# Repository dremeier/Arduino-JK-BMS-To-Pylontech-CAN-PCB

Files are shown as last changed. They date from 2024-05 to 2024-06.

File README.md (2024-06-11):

<div align = center>

# [Arduino JK-BMS to Pylontech-CAN PCB](https://github.com/dremeier/Arduino-JK-BMS-To-Pylontech-CAN-PCB) 

PCB and Case for the Arduino JK-BMS To Pylontech-CAN converter for Deye Inverter
<br/>
  
 
<br/>
<div align = left>
  
## Arduino Firmware by Armin: https://github.com/ArminJo/JK-BMSToPylontechCAN 

#### If you find this program useful, please give it a star.

&#x1F30E; [Google Translate](https://translate.google.com/translate?sl=en&u=https://github.com/dremeier/Arduino-JK-BMS-To-Pylontech-CAN-PCB)

## Features 
- Buck converter for up to 65 Volt to 5V.
- RS232-stream from the BMS translate from 3,3V to 5V and are galvanic seperated.
- MCU ATmega644P with [MightyCore](https://github.com/MCUdude/MightyCore) Bootloader.
- Connectors are JST PH S4B-PH-K 1x04 P2.00mm Horizontal.
- RJ45 connector Amphenol 54602-x08 Horizontal.
- Designed with KiCad 8.

[Files to print your own case](JK-BMS-CAN_Case/)

## Pictures

### PCB Layout
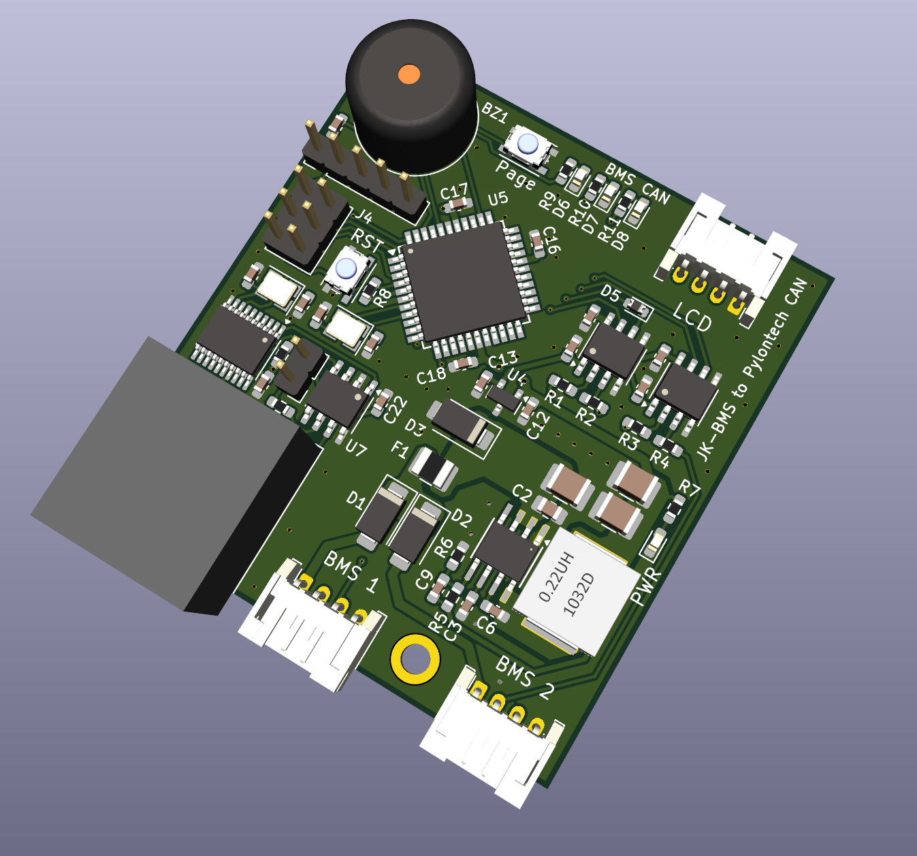
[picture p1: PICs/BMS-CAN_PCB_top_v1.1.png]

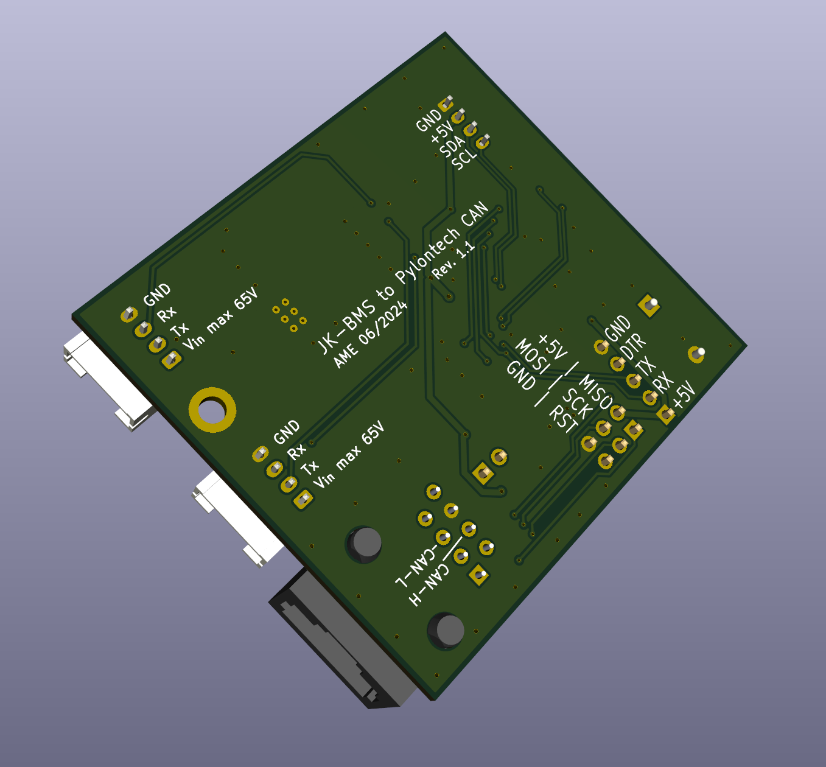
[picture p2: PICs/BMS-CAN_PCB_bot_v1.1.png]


### Aufbau im Gehäuse
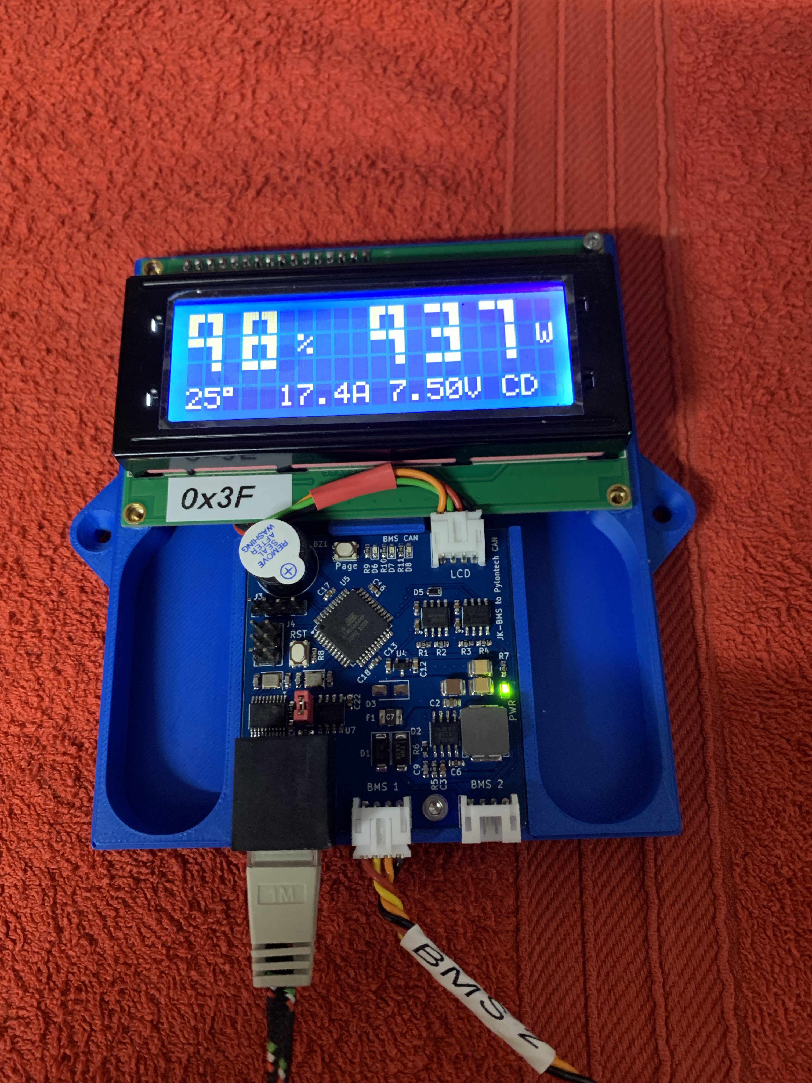
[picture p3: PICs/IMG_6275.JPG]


### Fertig installiert mit einem BMS, die Verarbeitung für das 2. BMS ist in Arbeit
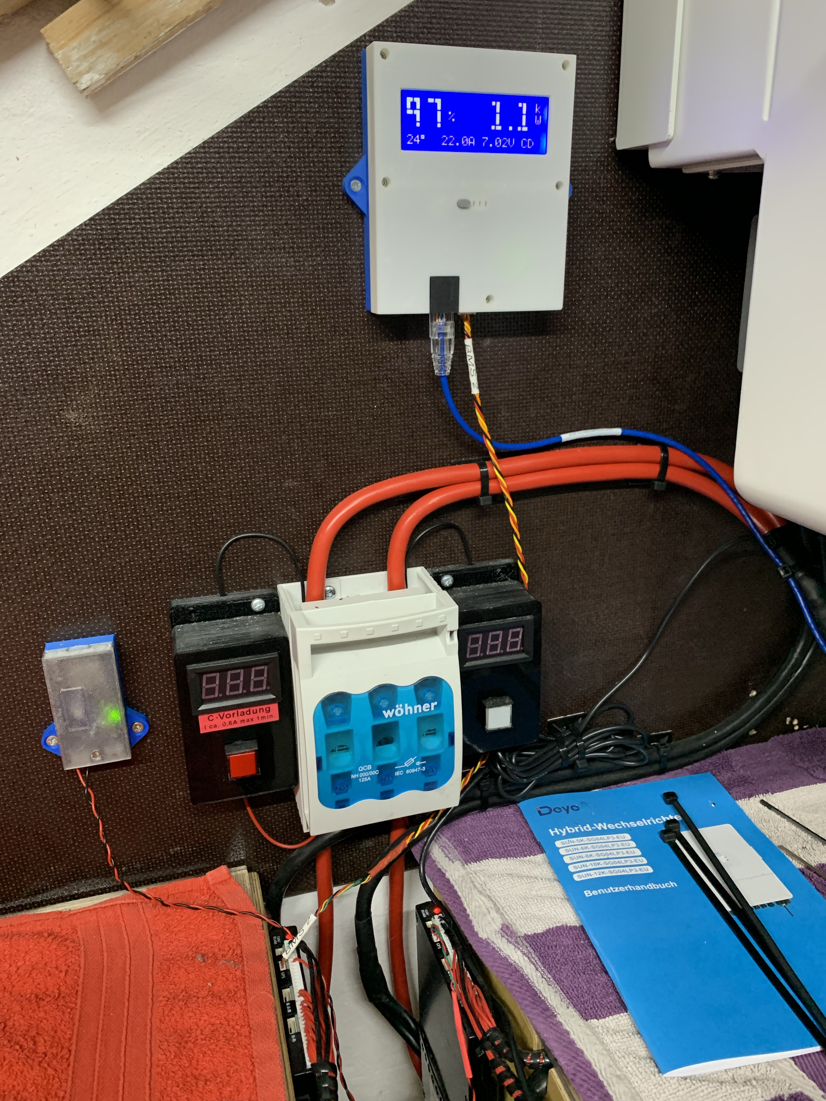
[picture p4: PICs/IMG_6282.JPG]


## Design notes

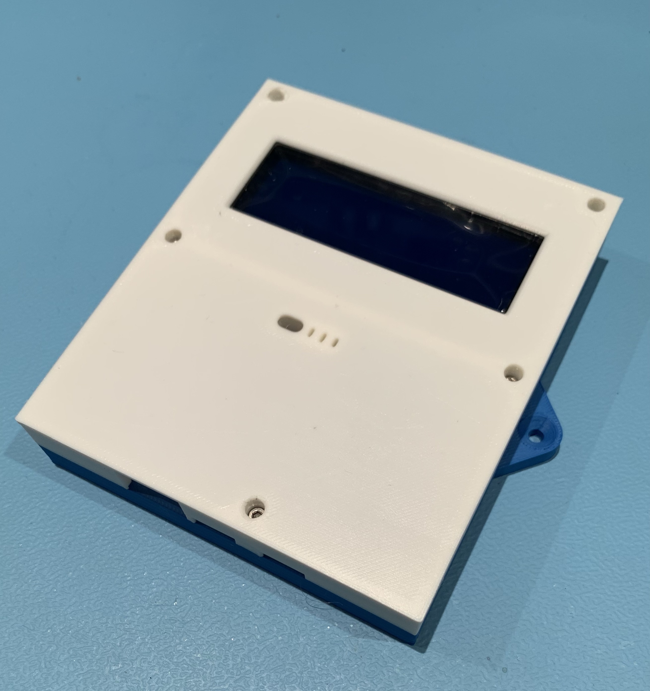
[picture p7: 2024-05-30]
PICs/BMS-CAN_Case.JPG

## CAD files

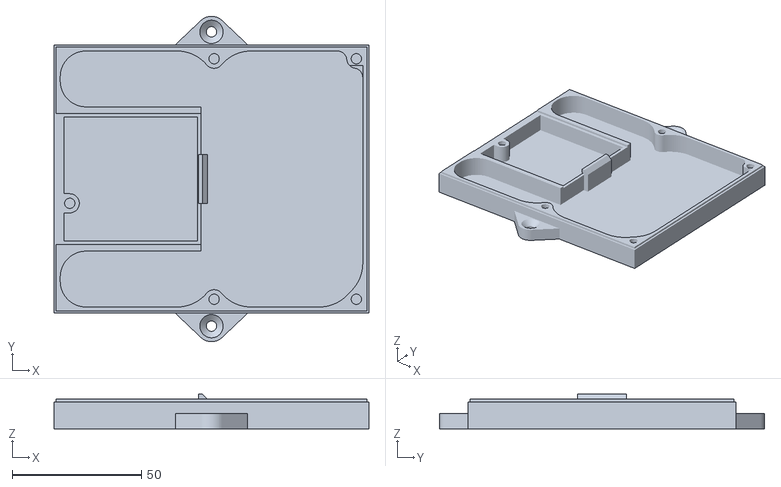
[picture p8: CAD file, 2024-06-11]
JK-BMS-CAN_Case/Boden.stl
121.8 x 125.8 x 13.5

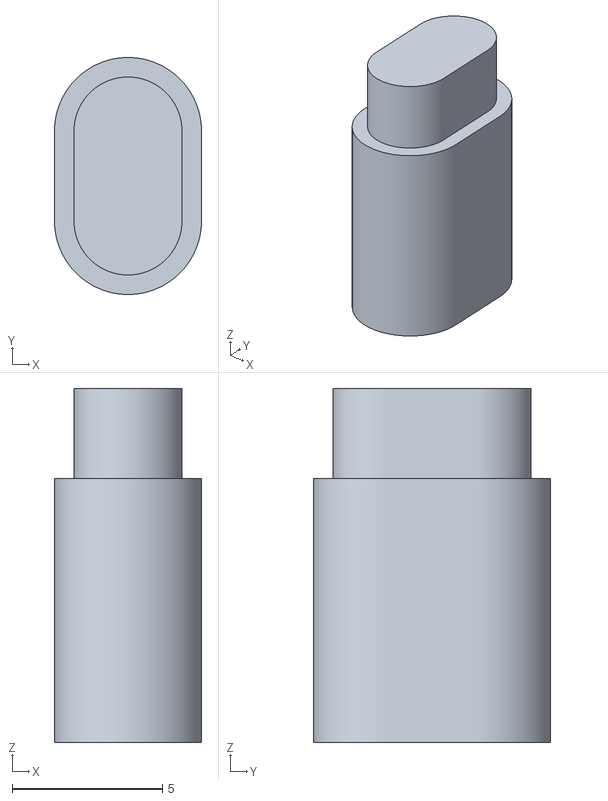
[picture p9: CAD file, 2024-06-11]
JK-BMS-CAN_Case/Taster.stl
4.90 x 7.90 x 11.8

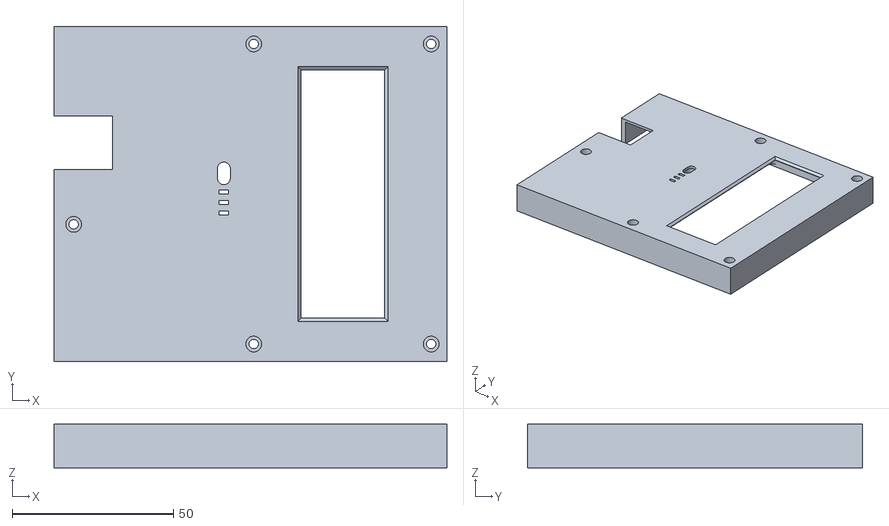
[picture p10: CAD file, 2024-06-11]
JK-BMS-CAN_Case/Deckel.stl
121.8 x 103.8 x 13.5

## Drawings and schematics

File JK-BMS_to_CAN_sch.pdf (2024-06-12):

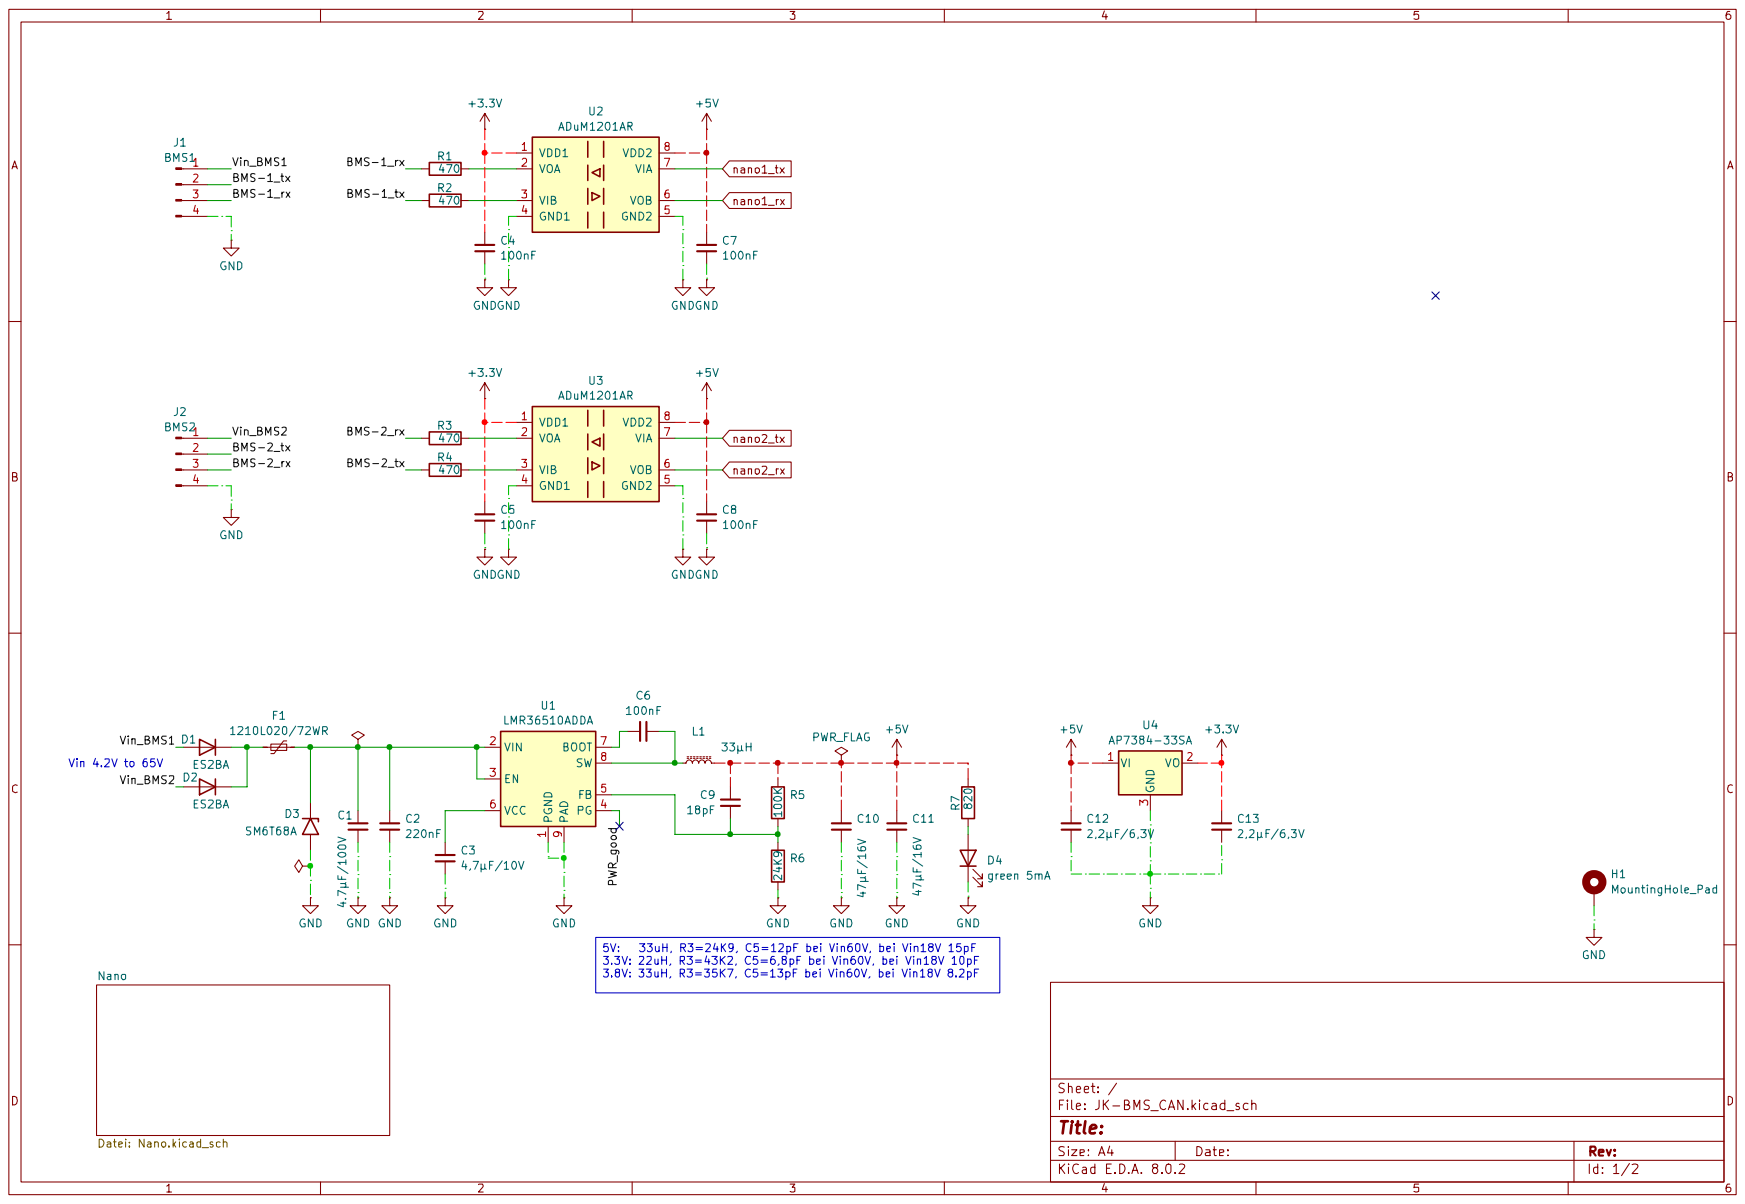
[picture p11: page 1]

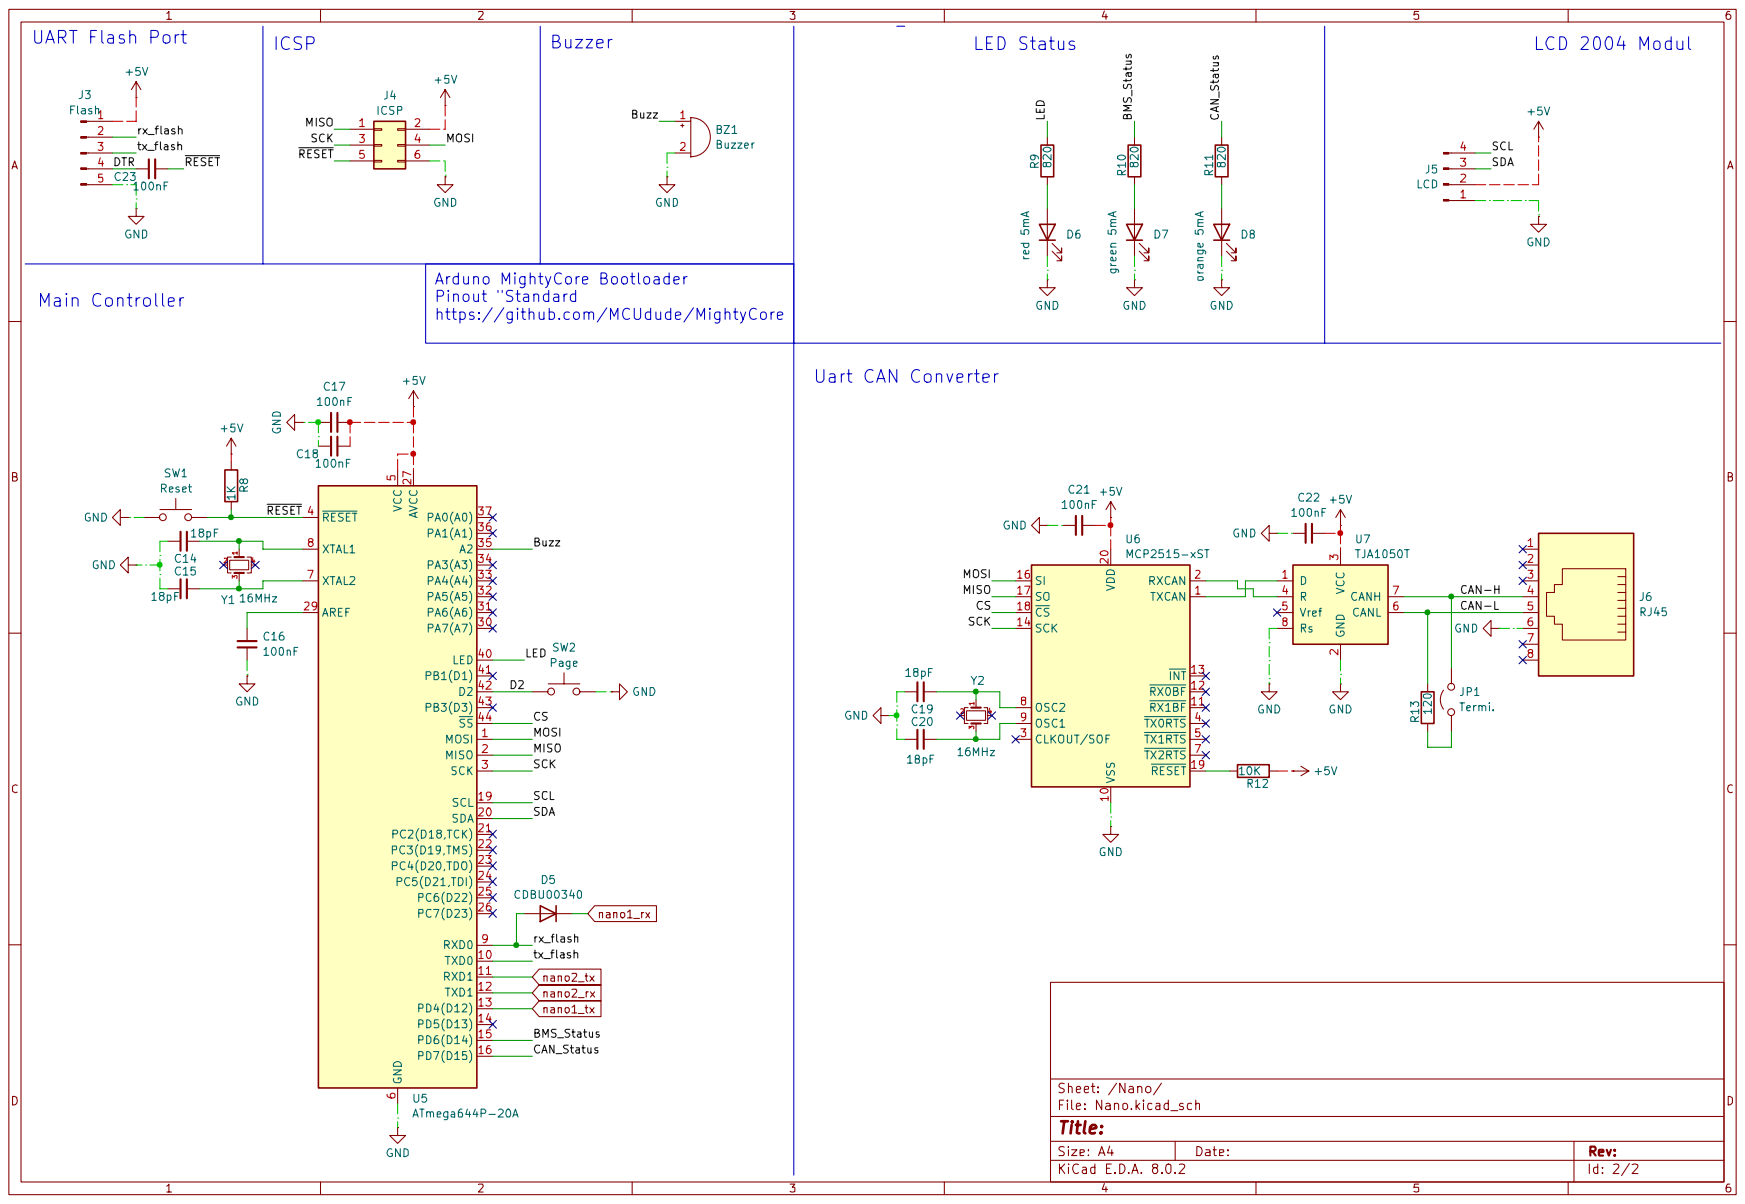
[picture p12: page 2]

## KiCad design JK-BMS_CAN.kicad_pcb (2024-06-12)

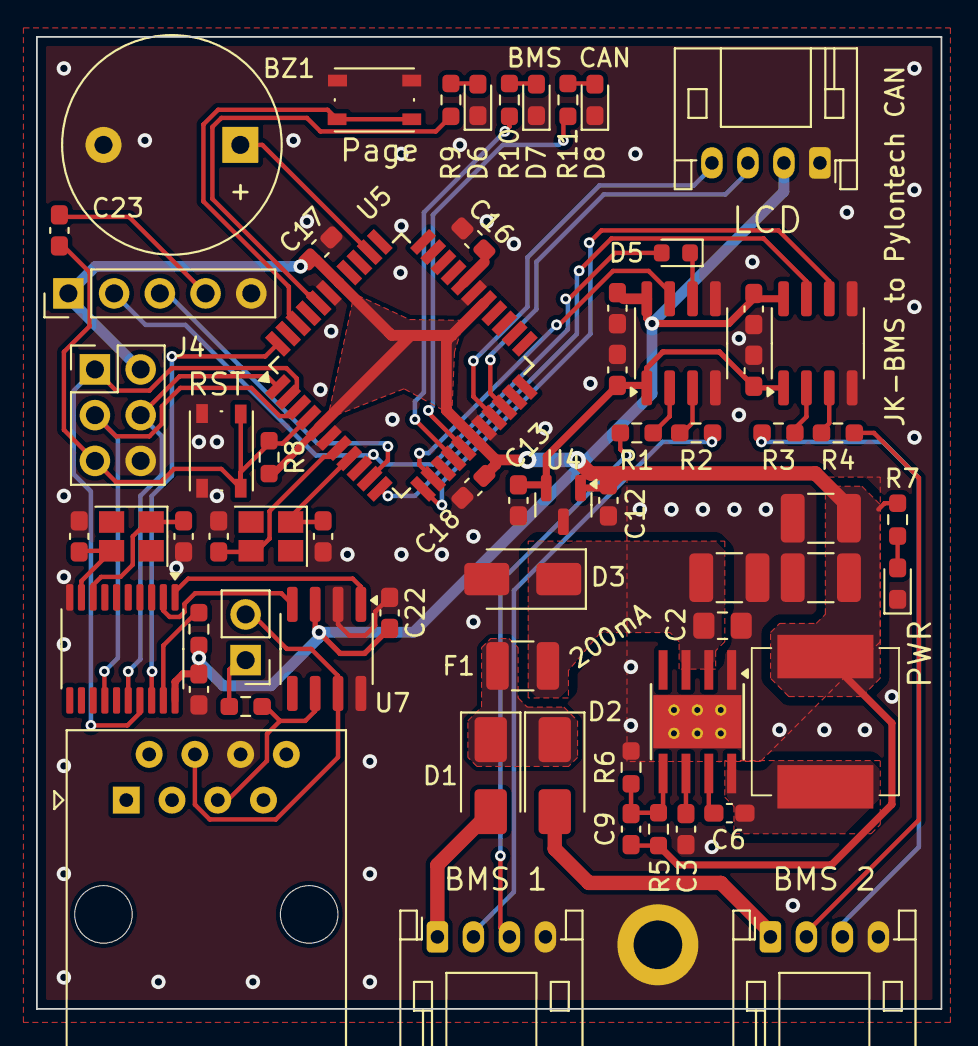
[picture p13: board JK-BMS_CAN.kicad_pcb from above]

Board: 2 copper layers, 50.2 x 54.0 mm, 66 parts (0 on the bottom side), 53 nets.

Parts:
BZ1: Buzzer; Buzzer_12x9.5RM7.6
C1: 4.7µF/100V; C_1210_3225Metric_Pad1.33x2.70mm_HandSolder
C2: 220nF; C_0805_2012Metric_Pad1.18x1.45mm_HandSolder
C3: 4,7µF/10V; C_0603_1608Metric_Pad1.08x0.95mm_HandSolder
C4, C5, C6, C7, C8, C16, C17, C18, C21, C22, C23: 100nF; C_0603_1608Metric_Pad1.08x0.95mm_HandSolder
C9, C14, C15, C19, C20: 18pF; C_0603_1608Metric_Pad1.08x0.95mm_HandSolder
C10, C11: 47µF/16V; C_1210_3225Metric_Pad1.33x2.70mm_HandSolder
C12, C13: 2,2µF/6,3V; C_0603_1608Metric_Pad1.08x0.95mm_HandSolder
D1, D2: ES2BA; D_SMA
D3: SM6T68A; D_SMA
D4, D7: green 5mA; LED_0603_1608Metric_Pad1.05x0.95mm_HandSolder
D5: CDBU00340; D_0603_1608Metric
D6: red 5mA; LED_0603_1608Metric_Pad1.05x0.95mm_HandSolder
D8: orange 5mA; LED_0603_1608Metric_Pad1.05x0.95mm_HandSolder
F1: 1210L020/72WR; Fuse_1210_3225Metric
H1: MountingHole_Pad; MountingHole_2.7mm_M2.5_ISO7380_Pad
J1: BMS1; JST_PH_S4B-PH-K_1x04_P2.00mm_Horizontal
J2: BMS2; JST_PH_S4B-PH-K_1x04_P2.00mm_Horizontal
J3: Flash; PinHeader_1x05_P2.54mm_Vertical
J4: ICSP; PinHeader_2x03_P2.54mm_Vertical
J5: LCD; JST_PH_S4B-PH-K_1x04_P2.00mm_Horizontal
J6: RJ45; RJ45_Amphenol_54602-x08_Horizontal
JP1: Termi.; PinHeader_1x02_P2.54mm_Vertical
L1: 33µH; IHLP3232DZER330M11
R1, R2, R3, R4: 470; R_0603_1608Metric_Pad0.98x0.95mm_HandSolder
R5: 100K; R_0603_1608Metric_Pad0.98x0.95mm_HandSolder
R6: 24K9; R_0603_1608Metric_Pad0.98x0.95mm_HandSolder
R7, R9, R10, R11: 820; R_0603_1608Metric_Pad0.98x0.95mm_HandSolder
R8: 1K; R_0603_1608Metric_Pad0.98x0.95mm_HandSolder
R12: 10K; R_0603_1608Metric_Pad0.98x0.95mm_HandSolder
R13: 120; R_0603_1608Metric_Pad0.98x0.95mm_HandSolder
SW1: Reset; SW_Push_1P1T_NO_Vertical_Wuerth_434133025816
SW2: Page; SW_Push_1P1T_NO_Vertical_Wuerth_434133025816
U1: LMR36510ADDA; Texas_HTSOP-8-1EP_3.9x4.9mm_P1.27mm_EP2.95x4.9mm_Mask2.4x3.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
U2, U3: ADuM1201AR; SOIC-8_3.9x4.9mm_P1.27mm
U4: AP7384-33SA; SOT-23
U5: ATmega644P-20A; TQFP-44_10x10mm_P0.8mm
U6: MCP2515-xST; TSSOP-20_4.4x6.5mm_P0.65mm
U7: TJA1050T; SOIC-8_3.9x4.9mm_P1.27mm
Y1, Y2: 16MHz; Crystal_SMD_Abracon_ABM8AIG-4Pin_3.2x2.5mm

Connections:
+3.3V: C4.1, C5.1, C13.1, U2.1 (VDD1), U3.1 (VDD1), U4.2 (VO)
+5V: C7.1, C8.1, C9.2, C10.1, C11.1, C12.1, C17.1, C18.1, C21.2, C22.2, J3.1, J4.2, J5.2, L1.2, R5.2, R7.1, R8.2, R12.2, U2.8 (VDD2), U3.8 (VDD2), U4.1 (VI), U5.5 (VCC), U5.17 (VCC), U5.27 (AVCC), U5.38 (VCC), U6.20 (VDD), U7.3 (VCC)
/BMS-1_rx: J1.3, R1.2
/BMS-1_tx: J1.2, R2.2
/BMS-2_rx: J2.3, R3.2
/BMS-2_tx: J2.2, R4.2
/Nano/BMS_Status: R10.1, U5.15 (PD6(D14))
/Nano/Buzz: BZ1.1 (+), U5.35 (A2)
/Nano/CAN-H: J6.4, JP1.2 (B), U7.7 (CANH)
/Nano/CAN-L: J6.5, R13.1, U7.6 (CANL)
/Nano/CAN_Status: R11.1, U5.16 (PD7(D15))
/Nano/CS: U5.44 (~SS), U6.18 (~CS)
/Nano/D2: SW2.1, U5.42 (D2)
/Nano/DTR: C23.2, J3.4
/Nano/LED: R9.1, U5.40 (LED)
/Nano/MISO: J4.1, U5.2 (MISO), U6.17 (SO)
/Nano/MOSI: J4.4, U5.1 (MOSI), U6.16 (SI)
/Nano/SCK: J4.3, U5.3 (SCK), U6.14 (SCK)
/Nano/SCL: J5.4, U5.19 (SCL)
/Nano/SDA: J5.3, U5.20 (SDA)
/Nano/rx_flash: D5.2 (A), J3.2, U5.9 (RXD0)
/Nano/tx_flash: J3.3, U5.10 (TXD0)
/Nano/~RESET: C23.1, J4.5, R8.1, SW1.2, U5.4 (~RESET)
/Vin_BMS1: D1.2 (A), J1.1
/Vin_BMS2: D2.2 (A), J2.1
GND: BZ1.2 (-), C1.2, C2.2, C3.2, C4.2, C5.2, C7.2, C8.2, C10.2, C11.2, C12.2, C13.2, C14.2, C15.2, C16.2, C17.2, C18.2, C19.2, C20.2, C21.1, C22.1, D3.2 (A2), D4.1 (K), D6.1 (K), D7.1 (K), D8.1 (K), H1.1, J1.4, J2.4, J3.5, J4.6, J5.1, J6.6, R6.1, SW1.1, SW2.2, U1.1 (PGND), U1.9 (PAD), U2.4 (GND1), U2.5 (GND2), U3.4 (GND1), U3.5 (GND2), U4.3 (GND), U5.6 (GND), U5.18 (GND), U5.28 (GND), U5.39 (GND), U6.10 (VSS), U7.2 (GND), U7.8 (Rs)
unnamed: D1.1 (K), D2.1 (K), F1.1
unnamed: C1.1, C2.1, D3.1 (A1), F1.2, U1.2 (VIN), U1.3 (EN)
unnamed: D4.2 (A), R7.2
unnamed: D6.2 (A), R9.2
unnamed: D7.2 (A), R10.2
unnamed: D8.2 (A), R11.2
unnamed: JP1.1 (A), R13.2
unnamed: C6.1, U1.7 (BOOT)
unnamed: C9.1, R5.1, R6.2, U1.5 (FB)
unnamed: C6.2, L1.1, U1.8 (SW)
unnamed: C3.1, U1.6 (VCC)
unnamed: R2.1, U2.3 (VIB)
unnamed: R1.1, U2.2 (VOA)
unnamed: R4.1, U3.3 (VIB)
unnamed: R3.1, U3.2 (VOA)
unnamed: C16.1, U5.29 (AREF)
unnamed: C14.1, U5.8 (XTAL1), Y1.1
unnamed: C15.1, U5.7 (XTAL2), Y1.3
unnamed: C20.1, U6.9 (OSC1), Y2.3
unnamed: C19.1, U6.8 (OSC2), Y2.1
unnamed: U6.2 (RXCAN), U7.4 (R)
unnamed: U6.1 (TXCAN), U7.1 (D)
unnamed: R12.1, U6.19 (~RESET)
nano1_rx: D5.1 (K), U2.6 (VOB)
nano1_tx: U2.7 (VIA), U5.13 (PD4(D12))
nano2_rx: U3.6 (VOB), U5.12 (TXD1)
nano2_tx: U3.7 (VIA), U5.11 (RXD1)

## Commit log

2024-05-30 first upload
    [Boden.stl, Deckel.stl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]
2024-05-31 changed the crystal to 16MHz
    [JK-BMS_CAN.kicad_pcb, Nano.kicad_sch]
2024-05-31 update the schematic
2024-05-31 Update the BOM
2024-06-11 updated the Case files
    [Deckel.stl, Taster.stl]
2024-06-11 changed the shape to fit the I2C-PCB
    [Boden.stl]
2024-06-11 changed to R1.1
    added DTR-line for easy flashing
    [JK-BMS_CAN-B_Cu.gbr, JK-BMS_CAN-B_Mask.gbr, JK-BMS_CAN-B_Paste.gbr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]
2024-06-11 added PCB pics for rev1.1
2024-06-12 changed to rev 1.1
    added DTR line for easy flashing
    [JK-BMS_CAN.kicad_pcb, JK-BMS_CAN.kicad_sch, Nano.kicad_sch]
